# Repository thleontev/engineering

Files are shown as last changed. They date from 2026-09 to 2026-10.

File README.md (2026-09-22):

# Engineering

Репозиторий инженерных проектов и разработок.

Здесь собраны законченные и демонстрационные проекты по электронике, встроенному ПО, CAD, прототипированию и подготовке изделий к производству.

## Проекты

### Fire Lamp

Адресный LED-светильник на базе ESP32-S3 и WLED.

В проекте объединены:

- механическая конструкция и CAD;
- проектирование схемы и печатной платы;
- силовая часть для адресной LED-матрицы;
- встроенное ПО и пользовательский модуль WLED;
- датчик движения и датчик освещённости;
- сборка, прототипирование и испытания.

→ [Fire Lamp](fire-lamp/)

## Принцип публикации

В репозитории размещаются только материалы, которые подходят для публичного просмотра и воспроизведения проекта. Рабочие внутренние документы, данные поставщиков, учётные данные и незавершённые эксперименты не публикуются.

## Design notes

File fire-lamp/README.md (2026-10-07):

# Fire Lamp

Fire Lamp — настольный адресный LED-светильник с контроллером на ESP32-S3, матрицей WS2812B 16×16 и прошивкой на базе WLED.

Проект объединяет механику, электронику и встроенное ПО в одном изделии.

## Известная проблема

Несколько раз ESP32-S3 перезапускался в момент включения питания LED-матрицы после долгого выключения. Одна из возможных причин — большой пусковой ток. На выходе питания матрицы установлен конденсатор C14 на 470 мкФ, при включении он быстро заряжается и может на короткое время просаживать питание. Для следующей версии платы C14 лучше оставить как опциональный элемент (DNP) и устанавливать только если он действительно нужен после проверки питания.

## Основные узлы

- ESP32-S3;
- адресная LED-матрица WS2812B 16×16, 256 светодиодов;
- контроллер LumaCore-S3-PWR;
- PIR-датчик движения;
- датчик освещённости BH1750;
- питание 5 В;
- WLED с пользовательским модулем автоматического ночного режима.

## Структура

- [cad](cad/) — открытая механическая модель в формате STEP;
- [pcb](pcb/) — схема и печатная плата контроллера;
- [firmware](firmware/) — пользовательский модуль WLED и конфигурация;
- [docs](docs/) — архитектура и описание инженерных решений.

## Архитектура

```text
                         Fire Lamp
                             │
              ┌──────────────┼──────────────┐
              │              │              │
              ▼              ▼              ▼
           Корпус         LED 16×16     Датчики
              │              │          PIR + BH1750
              │              │              │
              └──────────────┼──────────────┘
                             ▼
                     LumaCore-S3-PWR
                             │
                             ▼
                         ESP32-S3
                             │
                             ▼
                       WLED + usermod
```

## Что демонстрирует проект

Проект охватывает полный цикл разработки небольшого электронного изделия:

- механическая компоновка и CAD;
- интеграция платы, матрицы и датчиков в корпус;
- разработка принципиальной схемы;
- разводка PCB;
- силовое питание адресных светодиодов;
- разработка встроенного ПО;
- интеграция датчиков;
- настройка сценариев автоматического управления;
- прототипирование и проверка работы устройства.

## Механическая модель

- [Сборка Fire Lamp R1.2 в формате STEP](cad/fire-lamp-assembly.step)

## Галерея

Изображения Fire Lamp. Нажмите на изображение, чтобы открыть оригинал.

| | |
| --- | --- |
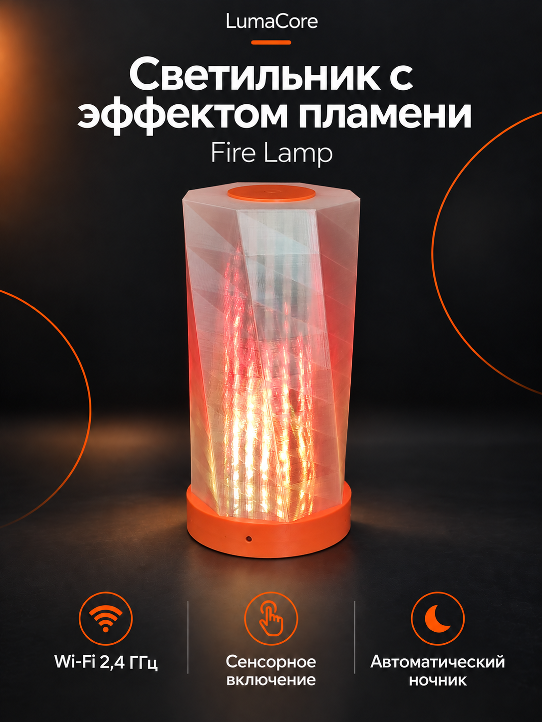
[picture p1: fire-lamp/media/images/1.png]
Fire Lamp — общий вид
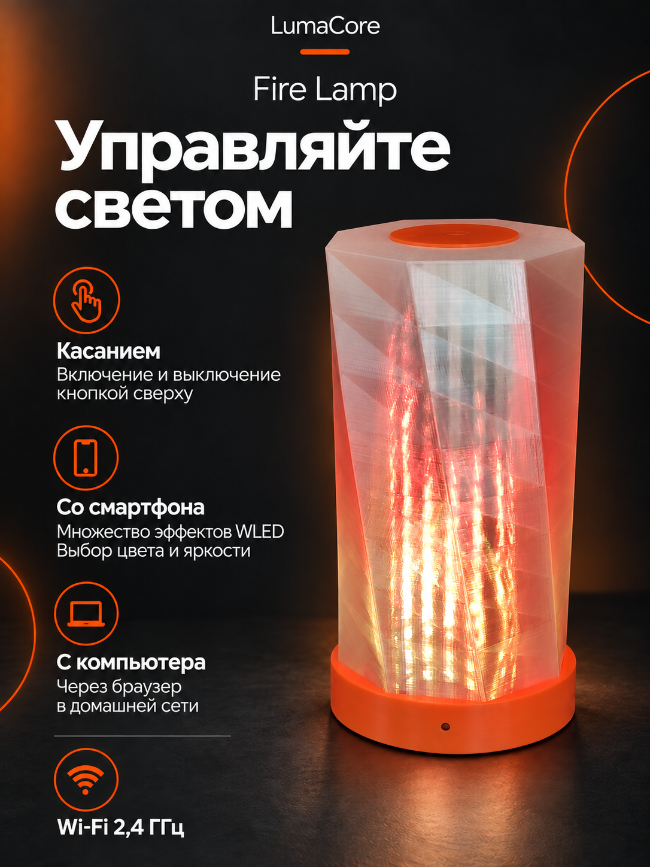
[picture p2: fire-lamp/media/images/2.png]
Управление светом
|  |  |
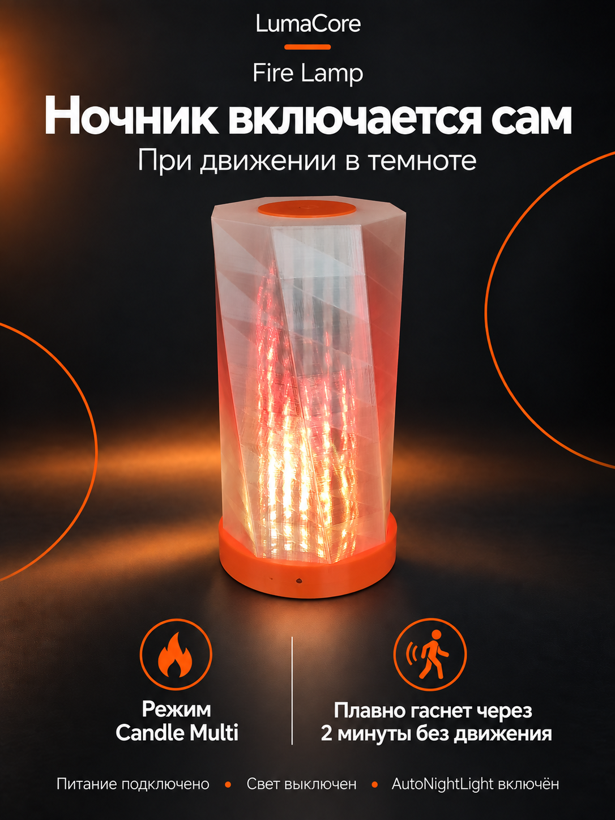
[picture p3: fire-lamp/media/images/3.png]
Автоматический ночник
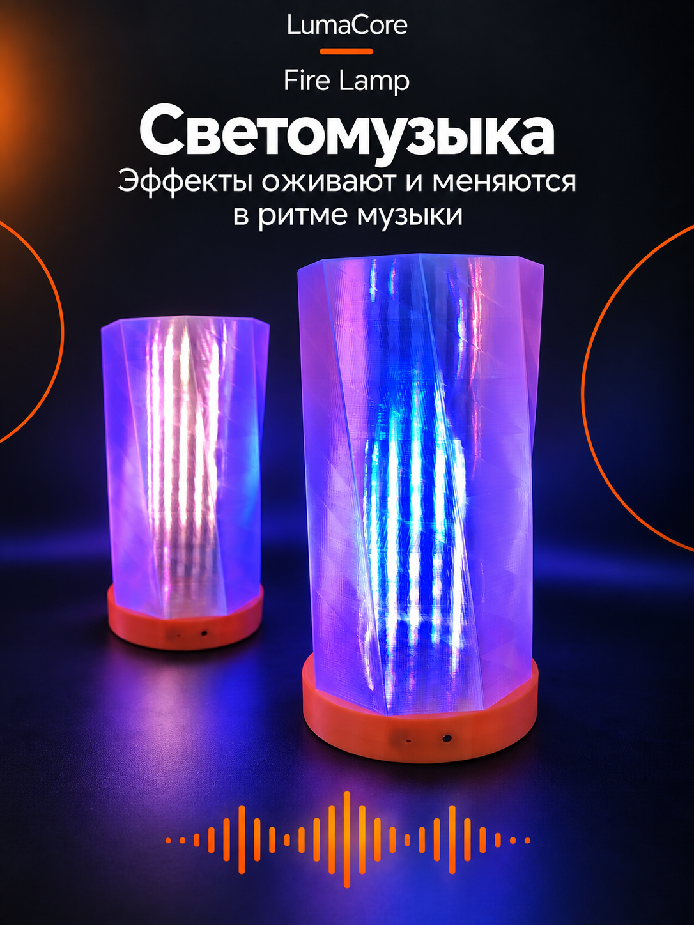
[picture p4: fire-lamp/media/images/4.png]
Светомузыка
|  |  |
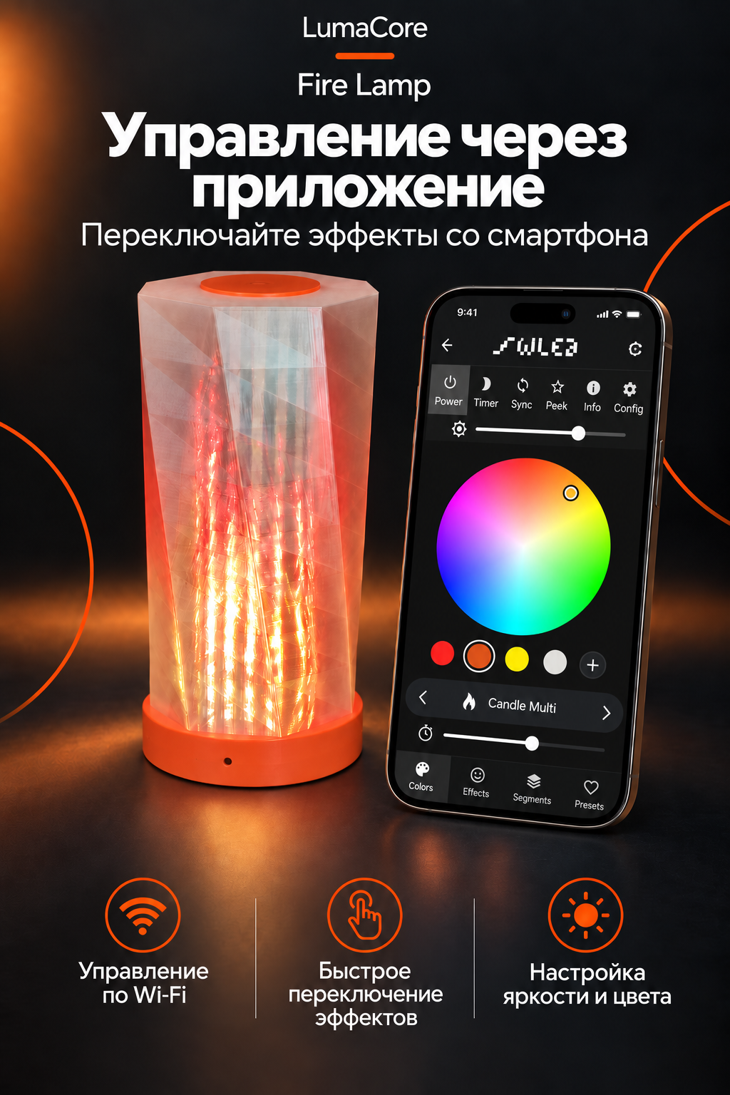
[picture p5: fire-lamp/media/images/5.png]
Управление через приложение
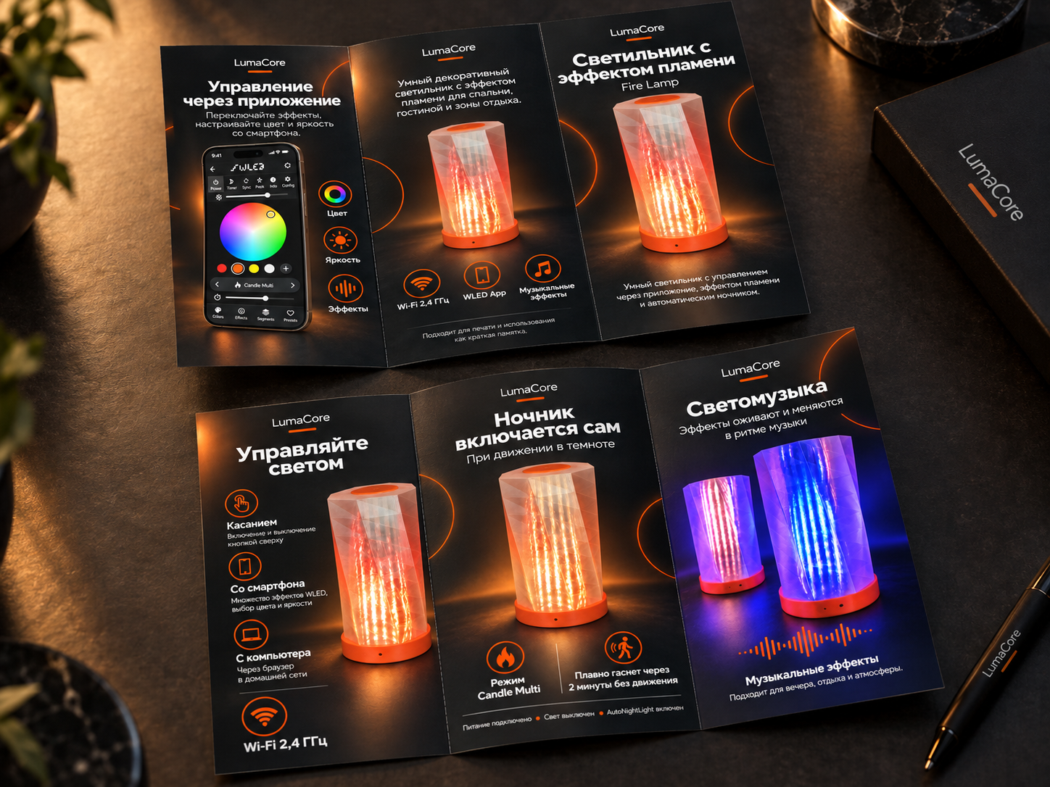
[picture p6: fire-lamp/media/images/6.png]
Буклет Fire Lamp
|  |  |
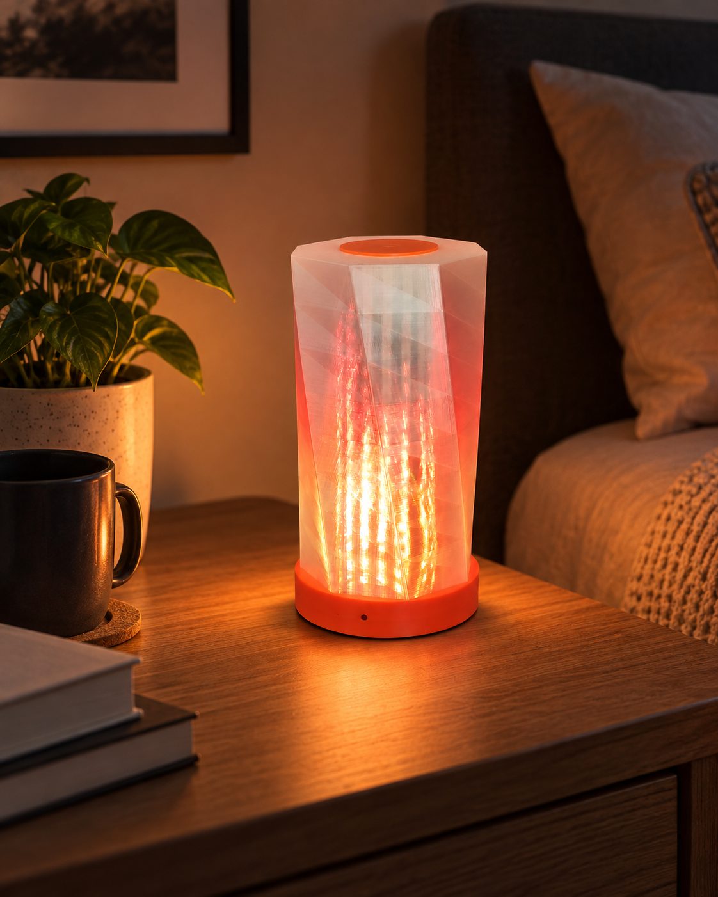
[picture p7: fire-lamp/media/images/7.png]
Fire Lamp в интерьере
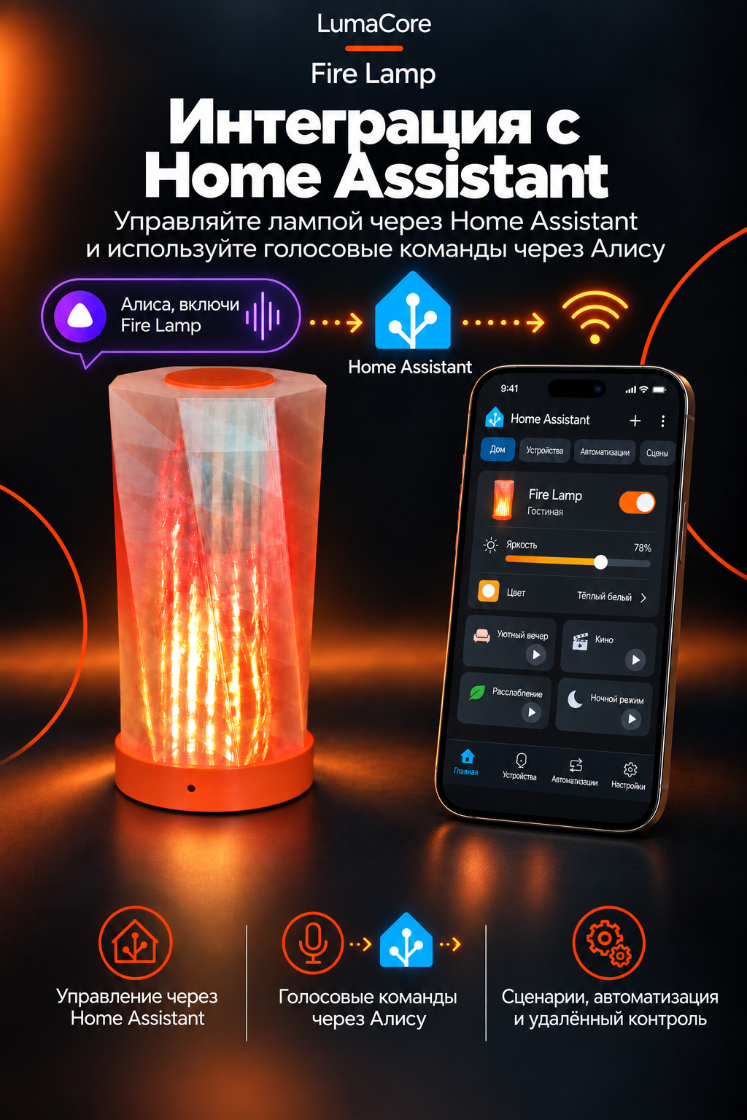
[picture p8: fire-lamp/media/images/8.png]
Интеграция с Home Assistant
|  |  |

## Видео

- [Видео history.mp4](media/video/history.mp4)
- [Демонстрация работы Fire Lamp](media/video/VID_20260911_115708.mp4)

## Состояние публикации

Публичная версия содержит только материалы, предназначенные для открытого использования. Нативные CAD-файлы КОМПАС-3D и внутренние рабочие материалы не публикуются.

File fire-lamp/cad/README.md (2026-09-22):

# CAD

Механические материалы Fire Lamp опубликованы в форматах STEP, STL и 3MF.

Нативные исходники КОМПАС-3D, Rhino и Grasshopper в этот репозиторий не включаются.

## Ревизия

Опубликована сборочная модель из каталога механической ревизии R1.2.

## STEP

- [Скачать полную сборку Fire Lamp в формате STEP](fire-lamp-assembly.step)

## Экспорт R1.2

Файлы из каталога экспорта механической ревизии R1.2:

- [Крышка — STL](export/R1.2/крышка.stl)
- [Плафон — STL](export/R1.2/плафон.stl)
- [Подставка — STL](export/R1.2/подставка.stl)
- [Центр — STL](export/R1.2/центр.stl)
- [Fire Lamp — 3MF](export/R1.2/fire%20lamp.3mf)

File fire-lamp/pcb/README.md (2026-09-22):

# PCB — LumaCore-S3-PWR

Электроника Fire Lamp построена на контроллере LumaCore-S3-PWR.

## Рендеры платы

### Верхняя сторона

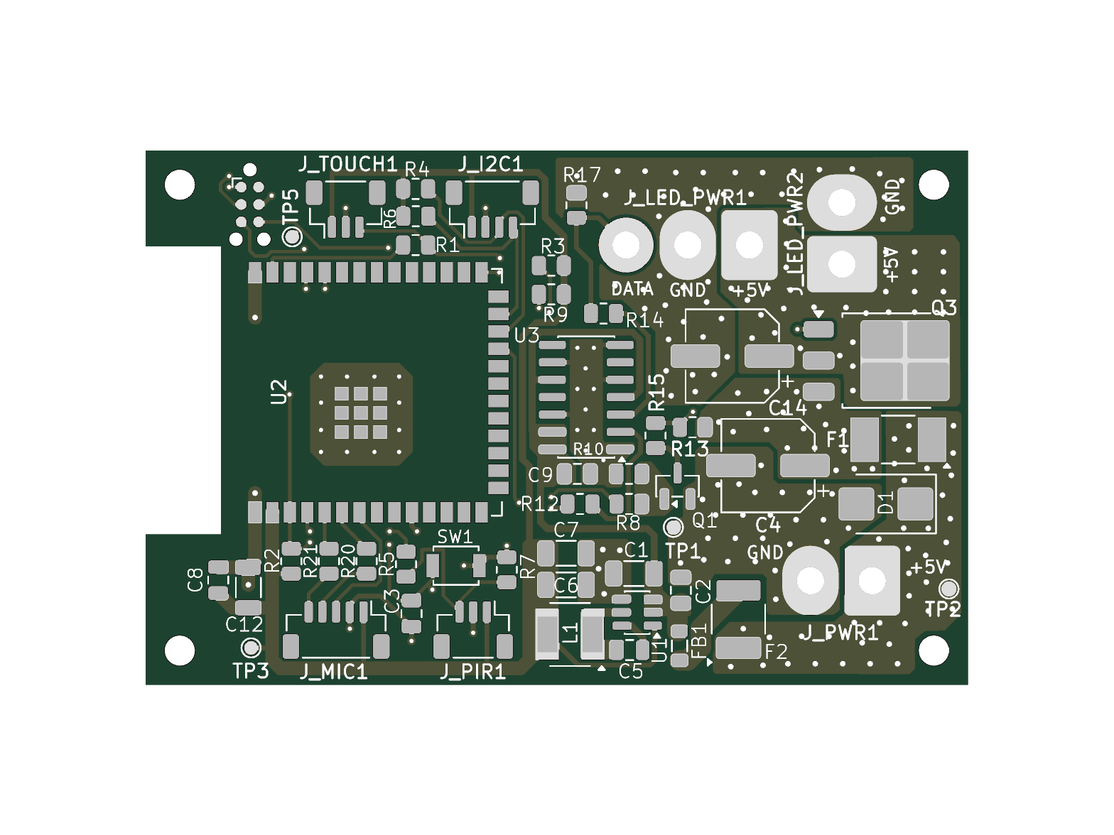
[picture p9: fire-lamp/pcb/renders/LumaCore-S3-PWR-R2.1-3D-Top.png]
LumaCore-S3-PWR R2.1 — верхняя сторона


### Нижняя сторона

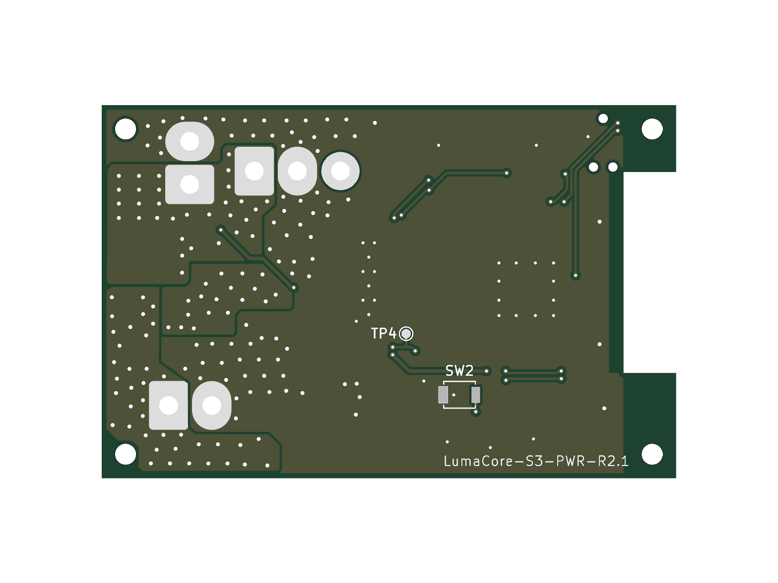
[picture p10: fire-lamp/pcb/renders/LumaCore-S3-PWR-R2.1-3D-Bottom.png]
LumaCore-S3-PWR R2.1 — нижняя сторона


## Исходники

В каталоге `source/` находятся исходники KiCad:

- проект;
- принципиальная схема;
- печатная плата.

В каталоге `production/` размещены открытые производственные данные, которые можно использовать для анализа платы и подготовки сборки.

## Основные параметры

- MCU: ESP32-S3-WROOM-1;
- питание изделия: 5 В;
- нагрузка: WS2812B 16×16;
- LED DATA: отдельный буферизированный цифровой выход;
- управление питанием LED;
- отдельное питание логики 3,3 В.

## Ревизия

Опубликованный набор PCB основан на LumaCore-S3-PWR R2.1.

Плата является частью проекта Fire Lamp, но может использоваться и как самостоятельная аппаратная платформа.

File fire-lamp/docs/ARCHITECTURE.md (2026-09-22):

# Архитектура Fire Lamp

## Назначение

Fire Lamp — автономный адресный светильник, в котором один контроллер управляет LED-матрицей и обрабатывает локальные датчики.

## Функциональная схема

```text
5 V DC
  │
  ├──────────────→ LED matrix WS2812B 16×16
  │
  └→ LumaCore-S3-PWR
          │
          ├→ ESP32-S3
          ├→ LED DATA
          ├→ PIR
          └→ BH1750
                │
                ▼
              WLED
                │
                └→ AutoNightLight usermod
```

## Контроллер

Основой электроники является LumaCore-S3-PWR — плата управления на ESP32-S3, рассчитанная на работу с адресными светодиодами и внешними датчиками.

## LED-матрица

Используется матрица WS2812B 16×16, всего 256 пикселей. Управление выполняется одним цифровым каналом DATA.

## Автоматический режим

Пользовательский модуль WLED использует два сигнала:

- PIR — наличие движения;
- BH1750 — текущая освещённость.

При низкой освещённости и обнаружении движения модуль может включить заданный WLED preset. После прекращения движения запускается задержка выключения. Ручное управление имеет приоритет над автоматикой.

## Разделение проекта

Механика, PCB и firmware публикуются раздельными каталогами, но относятся к одному изделию и должны рассматриваться совместно.

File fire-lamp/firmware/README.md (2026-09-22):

# Firmware

Fire Lamp использует WLED с пользовательским модулем LumaCore AutoNightLight.

Полный исходный код upstream WLED в этот репозиторий не дублируется. Здесь публикуются только изменения и настройки, относящиеся к Fire Lamp.

## Возможности AutoNightLight

Модуль объединяет:

- PIR-датчик движения;
- BH1750;
- автоматический запуск выбранного preset;
- задержку выключения;
- плавное включение и выключение;
- сохранение предыдущего состояния WLED в RAM;
- приоритет ручного управления.

## Логика

1. Проверяется уровень освещённости.
2. Если достаточно темно, разрешается реакция на PIR.
3. При обнаружении движения включается заданный preset.
4. После окончания движения запускается таймер.
5. По завершении таймера светильник выключается.
6. Если пользователь вручную выключил свет, автоматика не включает его повторно до завершения текущего события движения.

## Содержимое

- `usermod/` — исходный код пользовательского модуля;
- `config/` — пример конфигурации без паролей и данных конкретного устройства.

Конфигурационные файлы являются шаблонами. Учётные данные Wi-Fi, OTA, MQTT и другие секреты в репозиторий не включаются.

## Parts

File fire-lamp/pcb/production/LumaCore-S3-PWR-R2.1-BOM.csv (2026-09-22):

Refs | Qty | Value | Footprint | Manufacturer | MPN | Supplier | Description | Specification
C1 | 1 | 10uF | Capacitor_SMD:C_1206_3216Metric |  |  |  | Unpolarized capacitor, small symbol | 10uF; 10V; X5R; ±10%; 1206
C2, C5, C9, C12 | 4 | 100nF | Capacitor_SMD:C_0805_2012Metric |  |  |  | Unpolarized capacitor, small symbol | 100nF; 50V; X7R; ±10%; 0805
C3 | 1 | 1uF | Capacitor_SMD:C_0805_2012Metric |  |  |  | Unpolarized capacitor, small symbol | 1uF; 16V; X7R; ±10%; 0805
C4, C14 | 2 | 470uF | Capacitor_SMD:CP_Elec_6.3x7.7 |  | EEEFTA471XAP |  | 470uF 10V 105C SMD D6.3x7.7 | 470uF; 10V; 105°C; SMD 6.3x7.7mm
C6-C8 | 3 | 22uF | Capacitor_SMD:C_1206_3216Metric |  |  |  | Unpolarized capacitor, small symbol | 22uF; 10V; X7R; ±10%; 1206
D1 | 1 | SMBJ5.0A | Diode_SMD:D_SMB |  | SMBJ5.0A |  | Unidirectional TVS diode, 600W, 5V, SMB / DO-214AA | TVS; SMBJ5.0A; 5.0V; 600W; SMB (DO-214AA)
F1 | 1 | 10A, 125V, 2410 | LumaCore:Fuse_Littelfuse_NANO2_452_2410 |  | 0451010.MRL |  | 10A, 125V, 2410 | Fuse; 10A; 125V; 2410
F2 | 1 | PPTC 1.1A | LumaCore:Fuse_Polyfuse_Bourns_MF-MSMF110-16-2_1812 |  | MF-MSMF110/16-2 |  | PPTC resettable fuse, 1.1A hold, 2.2A trip, 16V, 1812 | PPTC; Ihold 1.1A; Vmax 16V; 1812
FB1 | 1 | Ferrite Bead | Inductor_SMD:L_0805_2012Metric |  | BLM21PG121SN1D |  | Ferrite bead, 120Ω @100MHz, 3A, 30mΩ max, 0805/2012, Murata BLM21PG series | Ferrite bead; 120Ω @100MHz; 3A; 0805
J_I2C1 | 1 | JST-SH 4pin | Connector_JST:JST_SH_BM04B-SRSS-TB_1x04-1MP_P1.00mm_Vertical |  |  |  | Generic connector, single row, 01x04, script generated (kicad-library-utils/schlib/autogen/connector/) | JST SH; 4 pin; 1.0mm; vertical SMD
J_MIC1 | 1 | JST-SH 5pin | Connector_JST:JST_SH_BM05B-SRSS-TB_1x05-1MP_P1.00mm_Vertical |  |  |  | Generic connector, single row, 01x05, script generated (kicad-library-utils/schlib/autogen/connector/) | JST SH; 5 pin; 1.0mm; vertical SMD
J_PIR1, J_TOUCH1 | 2 | JST-SH 3pin | Connector_JST:JST_SH_BM03B-SRSS-TB_1x03-1MP_P1.00mm_Vertical |  |  |  | Generic connector, single row, 01x03, script generated (kicad-library-utils/schlib/autogen/connector/) | JST SH; 3 pin; 1.0mm; vertical SMD
L1 | 1 | 3.9uH | LumaCore:L_4020_4030_Universal_LumaCore |  | MNR4030T3R9MT |  | Inductor | Inductor; 3.9uH; ±20%; current rating ≥3.3A; SMD 4x4mm
Q1 | 1 | 2N7002 | Package_TO_SOT_SMD:SOT-23 |  | 2N7002 |  | N-channel MOSFET, 60V, 115mA, SOT-23-3 | N-MOSFET; VDS ≥60V; ID ≥115mA; SOT-23-3
Q3 | 1 | PMOS_30V_6mR_TO252 | Package_TO_SOT_SMD:TO-252-3_TabPin2 |  | G050P03K |  | P-MOSFET, -30 V, RDS(on) ≤6 mΩ @ VGS=-4.5 V, TO-252, 1G-2D-3S | P-MOSFET; VDS -30V; RDS(on) ≤6mΩ @ VGS -4.5V; TO-252; 1G-2D-3S
R1, R5, R8, R12, R15 | 5 | 100 | Resistor_SMD:R_0805_2012Metric |  |  |  | Resistor, small symbol | 100Ω; ±1%; 0.125W; 0805; thick-film
R2, R9 | 2 | 10k | Resistor_SMD:R_0805_2012Metric |  |  |  | Resistor, small symbol | 10kΩ; ±1%; 0.125W; 0805; thick-film
R4, R6 | 2 | 4.7k | Resistor_SMD:R_0805_2012Metric |  |  |  | Resistor, small symbol | 4.7kΩ; ±1%; 0.125W; 0805; thick-film
R7, R10, R13, R17 | 4 | 100k | Resistor_SMD:R_0805_2012Metric |  |  |  | Resistor, small symbol | 100kΩ; ±1%; 0.125W; 0805; thick-film
R14 | 1 | 330 | Resistor_SMD:R_0805_2012Metric |  |  |  | Resistor, small symbol | 330Ω; ±1%; 0.125W; 0805; thick-film
R20, R21 | 2 | 33 | Resistor_SMD:R_0805_2012Metric |  |  |  | Resistor, small symbol | 33Ω; ±1%; 0.125W; 0805; thick-film
SW1 | 1 | Reset | Button_Switch_SMD:SW_SPST_B3U-1000P |  | B3U-1000P |  | Push button switch, generic, two pins | Tactile switch; SPST; B3U-1000P; SMD
U1 | 1 | AP63203WU | Package_TO_SOT_SMD:TSOT-23-6 |  | AP63203WU-7 |  | 2A, 1.1MHz Buck DC/DC Converter, fixed 3.3V output voltage, TSOT-23-6 | Buck DC/DC; 3.3V output; 2A; 1.1MHz; TSOT-23-6
U2 | 1 | ESP32-S3-WROOM-1 | LumaCore:ESP32-S3-WROOM-1 |  | ESP32-S3-WROOM-1(16R8) |  | 2.4 GHz WiFi (802.11 b/g/n) and Bluetooth ® 5 (LE) module Built around ESP32S3 series of SoCs, Xtensa ® dualcore 32bit LX7 microprocessor Flash up to 16 MB, PSRAM up to 8 MB 36 GPIOs, rich set of peripherals Onboard PCB antenna | ESP32-S3-WROOM-1(16R8); Wi-Fi/BLE; PCB antenna
U3 | 1 | 74AHCT125 | Package_SO:SOIC-14_3.9x8.7mm_P1.27mm |  | SN74AHCT125DR |  | Quadruple Bus Buffer Gates With 3-State Outputs | 74AHCT125; 5V logic buffer; SOIC-14

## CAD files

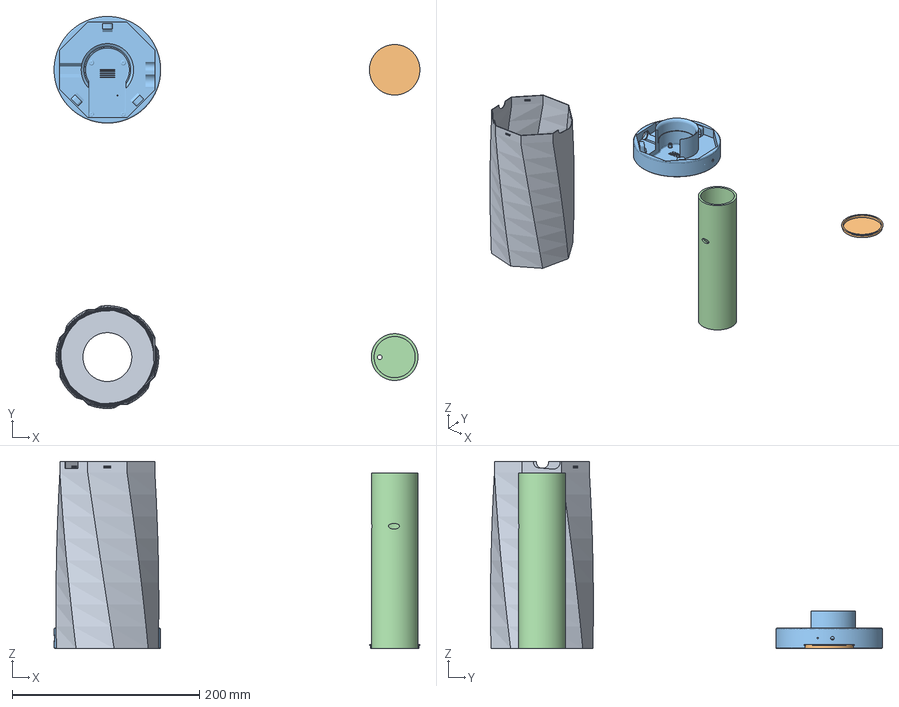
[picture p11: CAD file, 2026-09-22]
fire-lamp/cad/export/R1.2/fire lamp.3mf
391.2 x 419.2 x 200.0 mm
плафон.stl
крышка.stl
подставка.stl
центр.stl

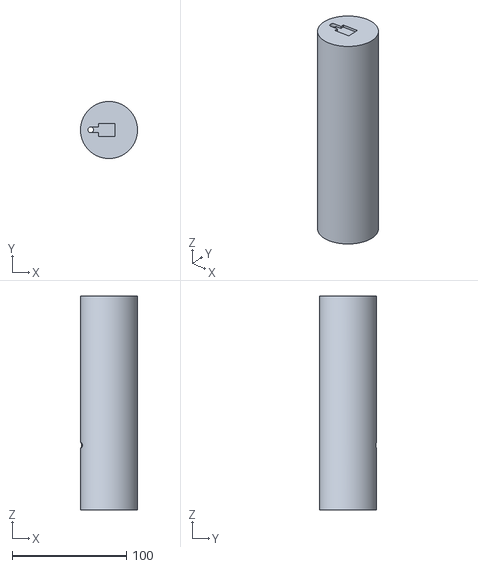
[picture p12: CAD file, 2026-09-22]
fire-lamp/cad/export/R1.2/центр.stl
50.0 x 50.0 x 187.5

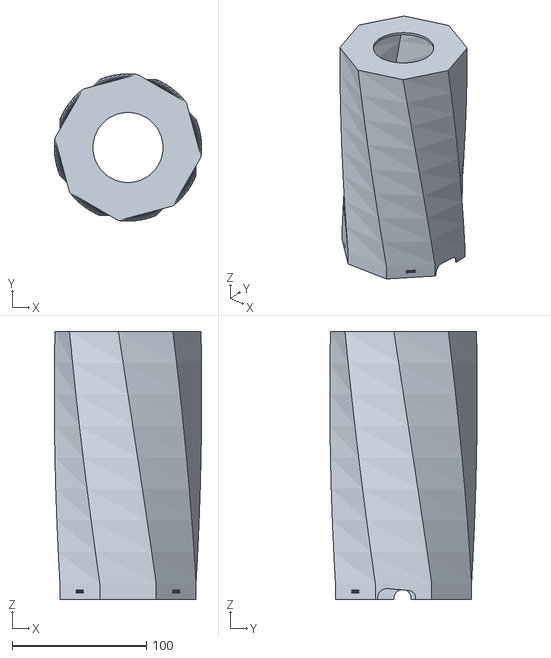
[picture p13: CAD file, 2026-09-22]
fire-lamp/cad/export/R1.2/плафон.stl
110.0 x 110.0 x 200.0

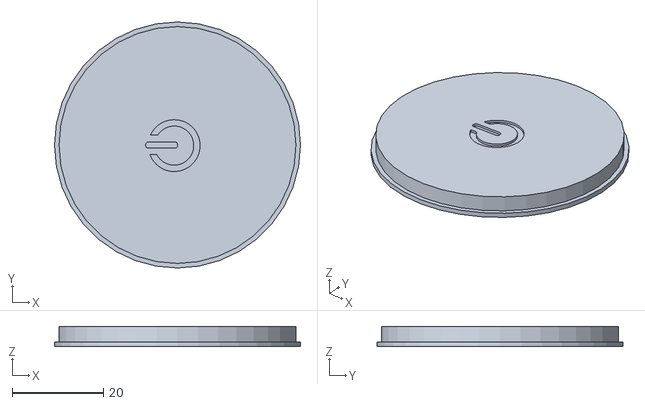
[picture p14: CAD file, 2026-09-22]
fire-lamp/cad/export/R1.2/крышка.stl
54.0 x 54.0 x 4.40

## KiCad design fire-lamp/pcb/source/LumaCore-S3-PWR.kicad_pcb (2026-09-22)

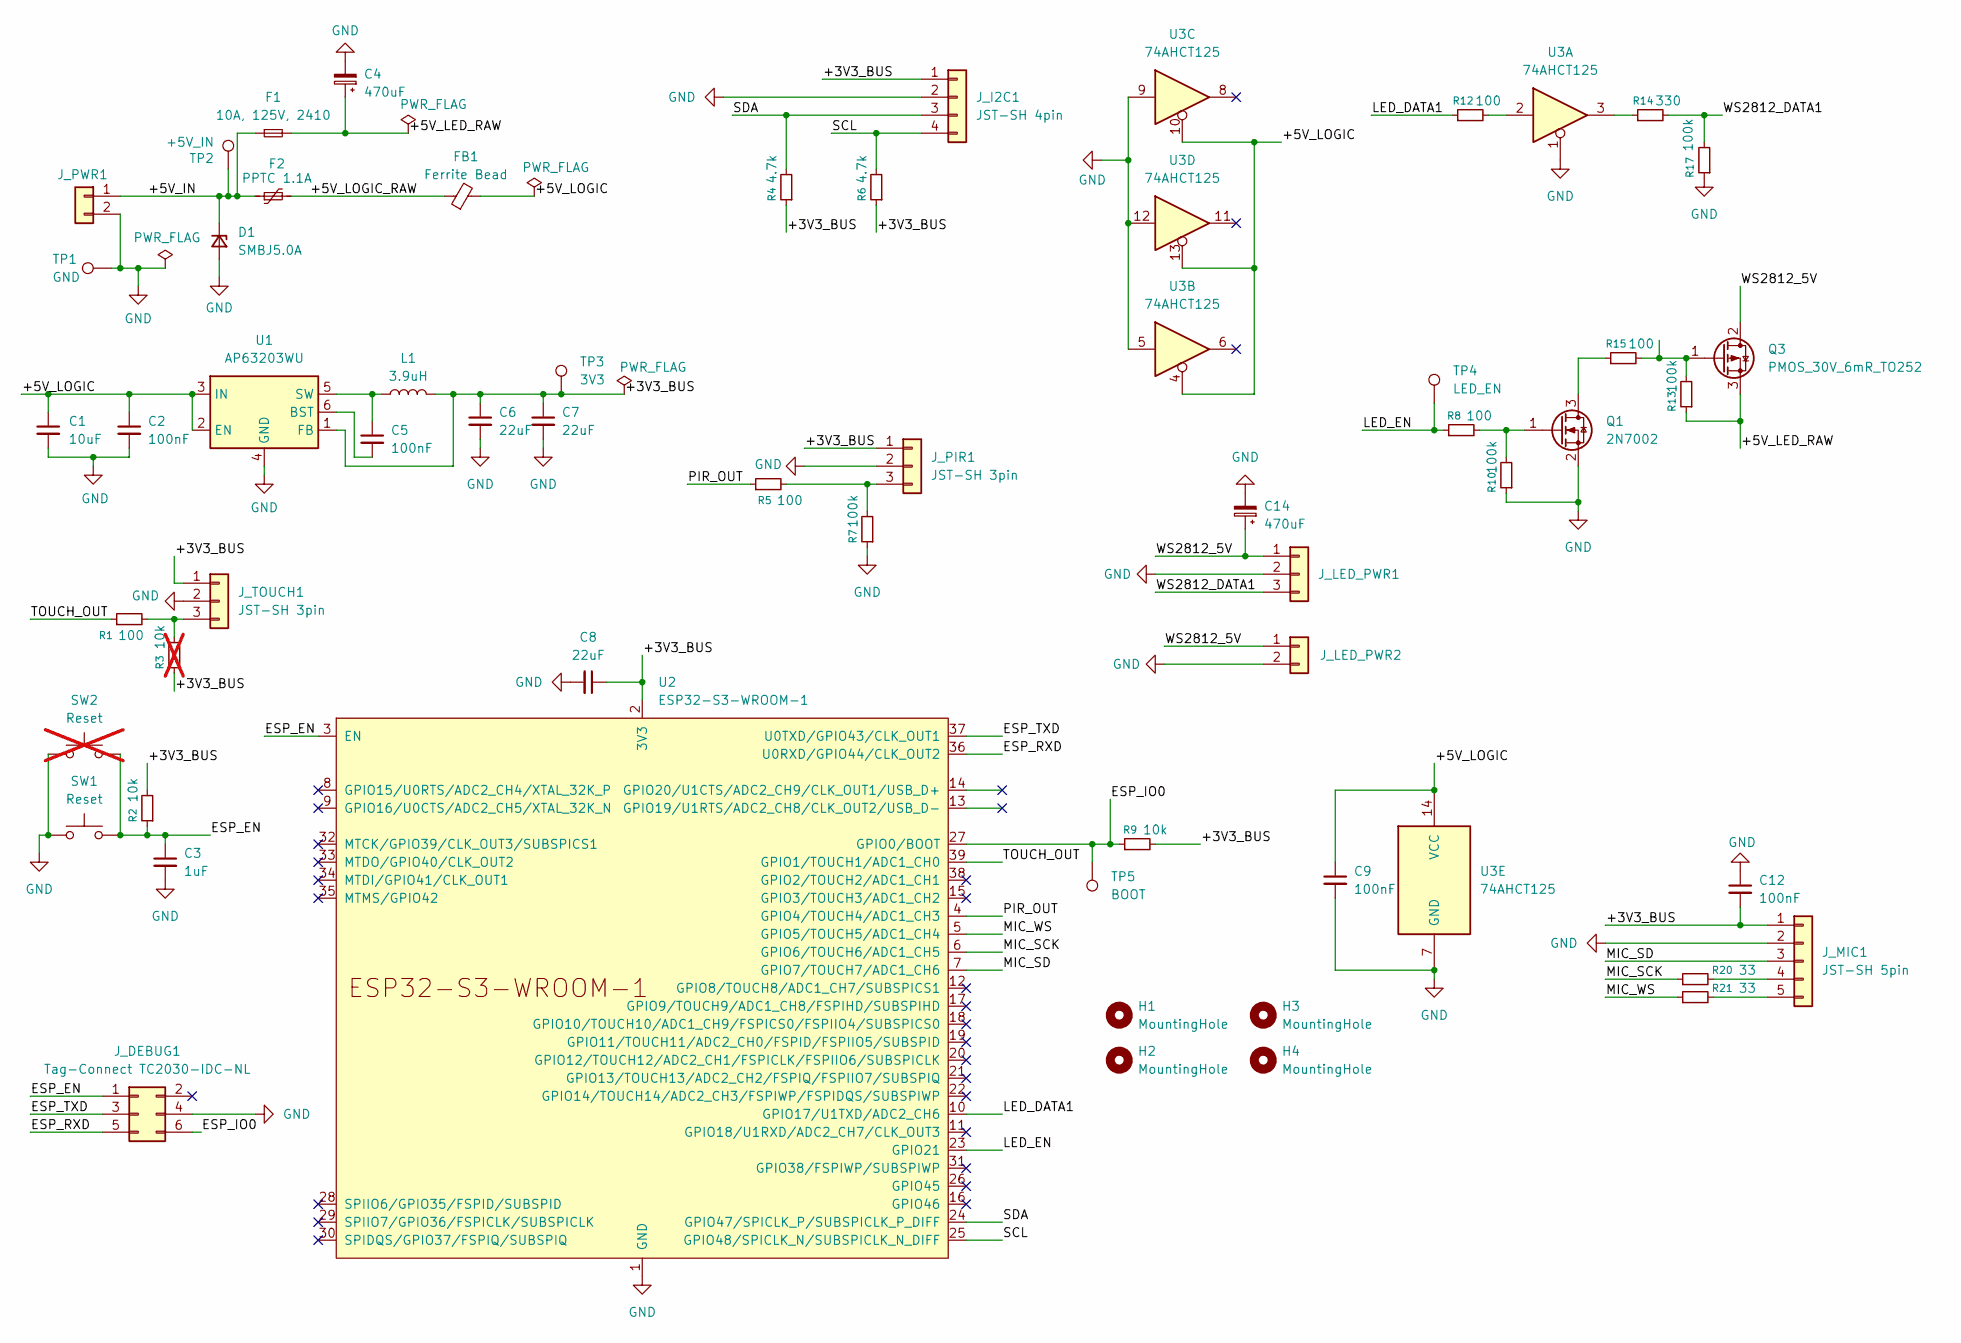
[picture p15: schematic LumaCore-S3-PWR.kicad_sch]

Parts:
C1: 10uF; C_1206_3216Metric
C2, C5, C9, C12: 100nF; C_0805_2012Metric
C3: 1uF; C_0805_2012Metric
C4, C14: 470uF; CP_Elec_6.3x7.7; MPN EEEFTA471XAP
C6, C7, C8: 22uF; C_1206_3216Metric
D1: SMBJ5.0A; D_SMB; MPN SMBJ5.0A
F1: 10A, 125V, 2410; Fuse_Littelfuse_NANO2_452_2410; MPN 0451010.MRL
F2: PPTC 1.1A; Fuse_Polyfuse_Bourns_MF-MSMF110-16-2_1812; MPN MF-MSMF110/16-2
FB1: Ferrite Bead; L_0805_2012Metric; MPN BLM21PG121SN1D
H1, H2, H3, H4: MountingHole; MountingHole_2.2mm_M2
J_DEBUG1: Tag-Connect TC2030-IDC-NL; Tag-Connect_TC2030-IDC-NL_2x03_P1.27mm_Vertical
J_I2C1: JST-SH 4pin; JST_SH_BM04B-SRSS-TB_1x04-1MP_P1.00mm_Vertical
J_LED_PWR1: SolderCable_1x03_AWG16_DATA_P4.50_D2.00
J_LED_PWR2: SolderCable_1x02_AWG16_P4.50_D2.00
J_MIC1: JST-SH 5pin; JST_SH_BM05B-SRSS-TB_1x05-1MP_P1.00mm_Vertical
J_PIR1: JST-SH 3pin; JST_SH_BM03B-SRSS-TB_1x03-1MP_P1.00mm_Vertical
J_PWR1: SolderCable_1x02_AWG16_P4.50_D2.00
J_TOUCH1: JST-SH 3pin; JST_SH_BM03B-SRSS-TB_1x03-1MP_P1.00mm_Vertical
L1: 3.9uH; L_4020_4030_Universal_LumaCore; MPN MNR4030T3R9MT
Q1: 2N7002; SOT-23; MPN 2N7002
Q3: PMOS_30V_6mR_TO252; TO-252-3_TabPin2; MPN G050P03K
R1, R5, R8, R12, R15: 100; R_0805_2012Metric
R2, R9: 10k; R_0805_2012Metric
R3: 10k; R_0805_2012Metric; not fitted
R4, R6: 4.7k; R_0805_2012Metric
R7, R10, R13, R17: 100k; R_0805_2012Metric
R14: 330; R_0805_2012Metric
R20, R21: 33; R_0805_2012Metric
SW1: Reset; SW_SPST_B3U-1000P; MPN B3U-1000P
SW2: Reset; SW_SPST_B3U-1000P; MPN B3U-1000P; not fitted
TP1: GND; TestPoint_Pad_D1.0mm
TP2: +5V_IN; TestPoint_Pad_D1.0mm
TP3: 3V3; TestPoint_Pad_D1.0mm
TP4: LED_EN; TestPoint_Pad_D1.0mm
TP5: BOOT; TestPoint_Pad_D1.0mm
U1: AP63203WU; TSOT-23-6; MPN AP63203WU-7
U2: ESP32-S3-WROOM-1; MPN ESP32-S3-WROOM-1(16R8)
U3: 74AHCT125; SOIC-14_3.9x8.7mm_P1.27mm; MPN SN74AHCT125DR

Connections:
/+3V3_BUS: C6.1, C7.1, C8.1, C12.2, J_I2C1.1, J_MIC1.1, J_PIR1.1, J_TOUCH1.1, L1.2, R2.2, R3.1, R4.1, R6.1, R9.2, TP3.1 (1_1), U1.1 (FB), U2.2 (3V3)
/+5V_IN: D1.1 (K), F1.1, F2.1, J_PWR1.1, TP2.1 (1_1)
/+5V_LED_RAW: C4.1, F1.2, Q3.3 (S), R13.1
/+5V_LOGIC: C1.1, C2.1, C9.1, FB1.2, U1.2 (EN), U1.3 (IN), U3.4, U3.10, U3.13, U3.14 (VCC)
/+5V_LOGIC_RAW: F2.2, FB1.1
/ESP_EN: C3.1, J_DEBUG1.1, R2.1, SW1.2, SW2.2, U2.3 (EN)
/ESP_IO0: J_DEBUG1.6, R9.1, TP5.1 (1_1), U2.27 (GPIO0/BOOT)
/ESP_RXD: J_DEBUG1.5, U2.36 (U0RXD/GPIO44/CLK_OUT2)
/ESP_TXD: J_DEBUG1.3, U2.37 (U0TXD/GPIO43/CLK_OUT1)
/LED_DATA1: R12.1, U2.10 (GPIO17/U1TXD/ADC2_CH6)
/LED_EN: R8.1, TP4.1 (1_1), U2.23 (GPIO21)
/MIC_SCK: R20.1, U2.6 (GPIO6/TOUCH6/ADC1_CH5)
/MIC_SD: J_MIC1.3, U2.7 (GPIO7/TOUCH7/ADC1_CH6)
/MIC_WS: R21.1, U2.5 (GPIO5/TOUCH5/ADC1_CH4)
/PIR_OUT: R5.1, U2.4 (GPIO4/TOUCH4/ADC1_CH3)
/SCL: J_I2C1.4, R6.2, U2.25 (GPIO48/SPICLK_N/SUBSPICLK_N_DIFF)
/SDA: J_I2C1.3, R4.2, U2.24 (GPIO47/SPICLK_P/SUBSPICLK_P_DIFF)
/TOUCH_OUT: R1.1, U2.39 (GPIO1/TOUCH1/ADC1_CH0)
/WS2812_5V: C14.1, J_LED_PWR1.1, J_LED_PWR2.1, Q3.2 (D)
/WS2812_DATA1: J_LED_PWR1.3, R14.2, R17.2
GND: C1.2, C2.2, C3.2, C4.2, C6.2, C7.2, C8.2, C9.2, C12.1, C14.2, D1.2 (A), J_DEBUG1.4, J_I2C1.2, J_LED_PWR1.2, J_LED_PWR2.2, J_MIC1.2, J_PIR1.2, J_PWR1.2, J_TOUCH1.2, Q1.2 (S), R7.1, R10.1, R17.1, SW1.1, SW2.1, TP1.1 (1_1), U1.4 (GND), U2.1 (GND), U2.40 (GND), U2.41 (GND), U3.1, U3.5, U3.7 (GND), U3.9, U3.12
unnamed: J_MIC1.4, R20.2
unnamed: J_MIC1.5, R21.2
unnamed: J_PIR1.3, R5.2, R7.2
unnamed: J_TOUCH1.3, R1.2, R3.2
unnamed: Q1.3 (D), R15.1
unnamed: Q1.1 (G), R8.2, R10.2
unnamed: Q3.1 (G), R13.2, R15.2
unnamed: R12.2, U3.2
unnamed: R14.1, U3.3
unnamed: C5.2, U1.6 (BST)
unnamed: C5.1, L1.1, U1.5 (SW)

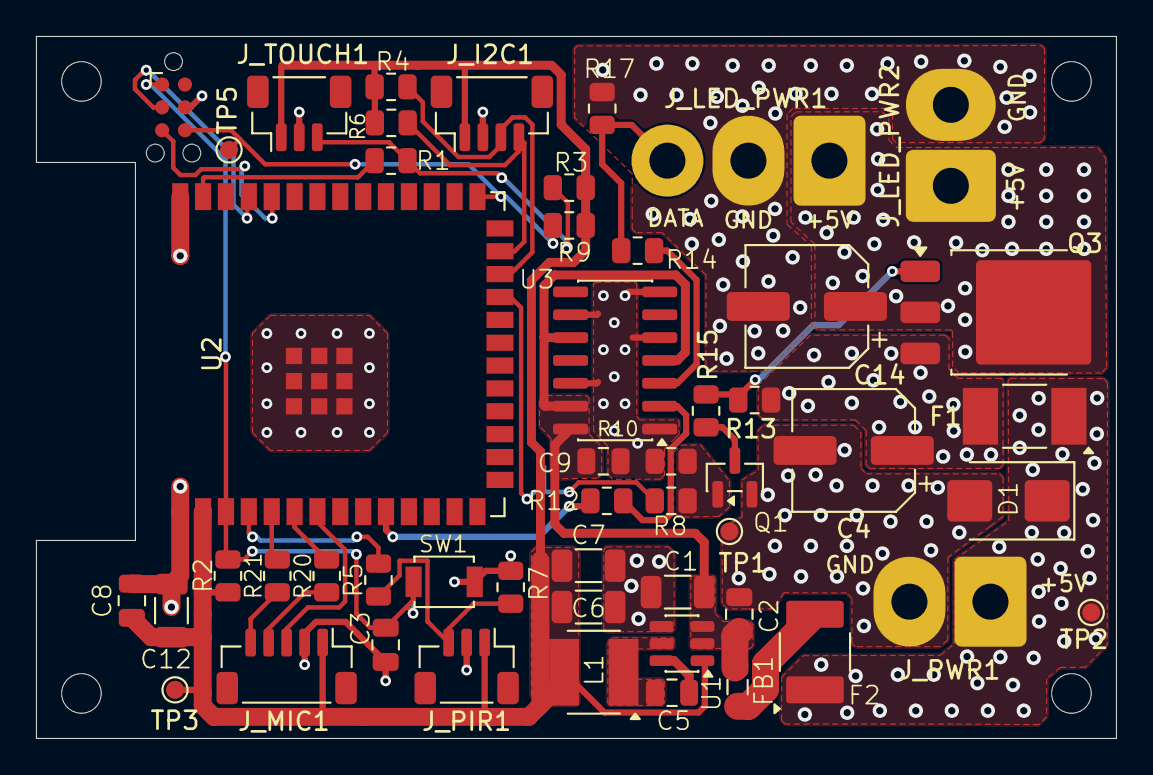
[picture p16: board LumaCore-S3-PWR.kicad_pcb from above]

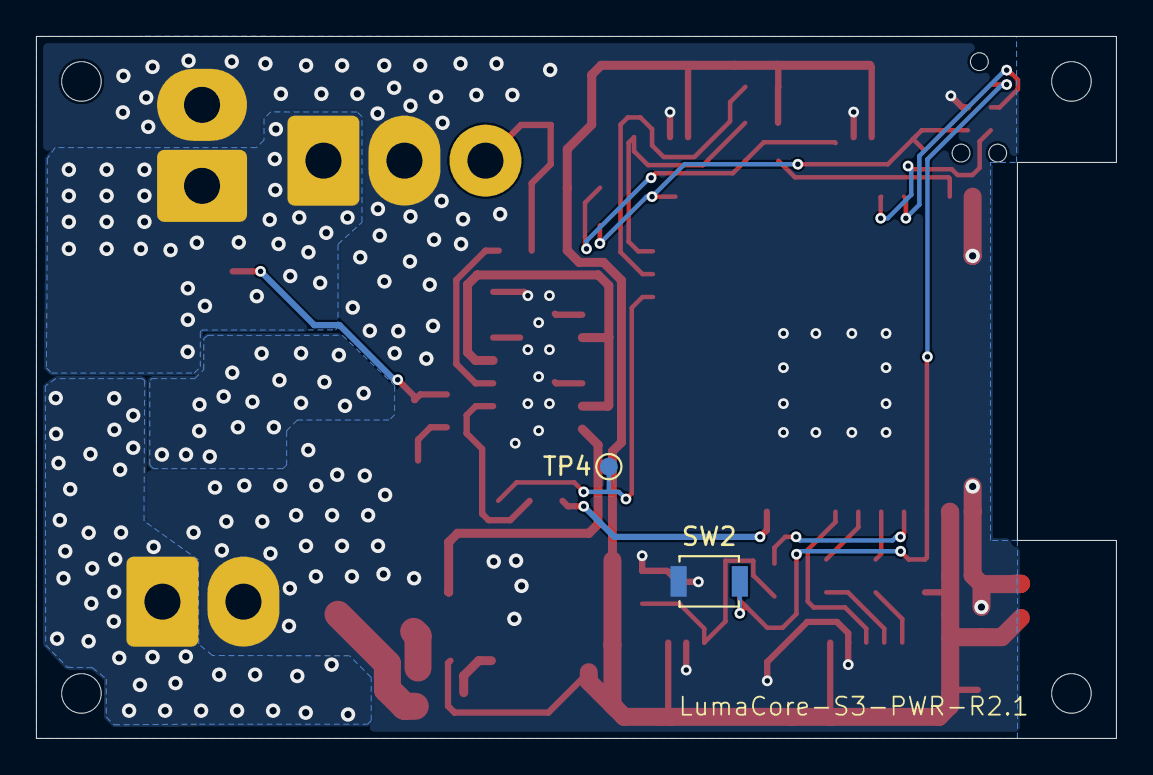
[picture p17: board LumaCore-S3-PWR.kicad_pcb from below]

Board: 2 copper layers, 60.0 x 39.0 mm, 57 parts (2 on the bottom side), 32 nets.

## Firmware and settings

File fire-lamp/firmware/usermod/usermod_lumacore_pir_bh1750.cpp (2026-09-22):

#include "usermod_lumacore_pir_bh1750.h"

#include <Wire.h>

static constexpr uint8_t BH1750_POWER_ON = 0x01;
static constexpr uint8_t BH1750_RESET = 0x07;
static constexpr uint8_t BH1750_CONTINUOUS_HIGH_RES_MODE = 0x10;
static constexpr uint16_t LUMACORE_PIR_CHECK_INTERVAL_MS = 100;
bool LumaCorePirBh1750Usermod::initI2c()
{
  sensorFound = false;
  luxValid = false;

  if (sdaPin < 0 || sclPin < 0) return false;

  PinManagerPinType i2cPins[2] = { { sdaPin, true }, { sclPin, true } };
  if (!PinManager::allocateMultiplePins(i2cPins, 2, PinOwner::HW_I2C)) {
    DEBUG_PRINTLN(F("LumaCore: could not allocate I2C pins."));
    return false;
  }

  i2cPinsAllocated = true;
  Wire.begin(sdaPin, sclPin);
  Wire.setClock(100000);
  return true;
}

bool LumaCorePirBh1750Usermod::writeBh1750Command(uint8_t command)
{
  Wire.beginTransmission(bh1750Address);
  Wire.write(command);
  return Wire.endTransmission() == 0;
}

bool LumaCorePirBh1750Usermod::initBh1750()
{
  if (!writeBh1750Command(BH1750_POWER_ON)) return false;
  writeBh1750Command(BH1750_RESET);
  return writeBh1750Command(BH1750_CONTINUOUS_HIGH_RES_MODE);
}

bool LumaCorePirBh1750Usermod::readBh1750Lux()
{
  if (!sensorFound) {
    sensorFound = initBh1750();
    if (!sensorFound) {
      luxValid = false;
      return false;
    }
  }

  uint8_t bytesRead = Wire.requestFrom(bh1750Address, static_cast<uint8_t>(2));
  if (bytesRead != 2) {
    sensorFound = false;
    luxValid = false;
    return false;
  }

  uint16_t raw = (static_cast<uint16_t>(Wire.read()) << 8) | Wire.read();
  lastLux = raw / 1.2f;
  luxValid = true;
  return true;
}

void LumaCorePirBh1750Usermod::readPir()
{
  if (!pirPinAllocated) {
    rawPirHigh = false;
    pirActive = false;
    return;
  }

  rawPirHigh = digitalRead(pirPin) == HIGH;
  pirActive = pirActiveHigh ? rawPirHigh : !rawPirHigh;
}

bool LumaCorePirBh1750Usermod::isDark() const
{
  return luxValid && lastLux < luxThreshold;
}

bool LumaCorePirBh1750Usermod::isPirOwnedState() const
{
  return nightLightState == NightLightState::AutoOn || nightLightState == NightLightState::WaitingOff;
}

void LumaCorePirBh1750Usermod::setNightLightState(NightLightState newState)
{
  nightLightState = newState;

  if (newState == NightLightState::WaitingOff) {
    if (!offTimerStart) offTimerStart = millis();
  } else {
    offTimerStart = 0;
  }
}

void LumaCorePirBh1750Usermod::clearPreviousState()
{
  p_free(previousStateJson);
  previousStateJson = nullptr;
  previousStateJsonLen = 0;
  previousStateSaved = false;
  previousCurrentPreset = 0;
  previousPresetCycCurr = 0;
  previousCurrentPlaylist = -1;
}

bool LumaCorePirBh1750Usermod::capturePreviousState()
{
  clearPreviousState();

  DynamicJsonDocument stateDoc(JSON_BUFFER_SIZE);
  JsonObject state = stateDoc.to<JsonObject>();
  serializeState(state);
  state["on"] = false;
  state.remove(F("ps"));
  state.remove(F("pl"));
  state.remove(F("psave"));
  state.remove(F("pdel"));

  if (stateDoc.overflowed()) {
    DEBUG_PRINTLN(F("LumaCore: previous state snapshot overflowed."));
    clearPreviousState();
    return false;
  }

  previousCurrentPreset = currentPreset;
  previousPresetCycCurr = presetCycCurr;
  previousCurrentPlaylist = currentPlaylist;
  previousStateJsonLen = measureJson(stateDoc) + 1;
  previousStateJson = static_cast<char*>(p_malloc(previousStateJsonLen));
  if (!previousStateJson) {
    DEBUG_PRINTLN(F("LumaCore: could not allocate previous state snapshot."));
    clearPreviousState();
    return false;
  }

  serializeJson(stateDoc, previousStateJson, previousStateJsonLen);
  previousStateSaved = true;
  return true;
}

bool LumaCorePirBh1750Usermod::restorePreviousStateKeepingOff()
{
  if (!previousStateSaved || !previousStateJson) return false;

  byte restoredPreset = previousCurrentPreset;
  byte restoredPresetCyc = previousPresetCycCurr;
  int16_t restoredPlaylist = previousCurrentPlaylist;

  DynamicJsonDocument stateDoc(JSON_BUFFER_SIZE);
  DeserializationError error = deserializeJson(stateDoc, previousStateJson);
  if (error) {
    DEBUG_PRINTLN(F("LumaCore: could not deserialize previous state snapshot."));
    clearPreviousState();
    return false;
  }

  JsonObject state = stateDoc.as<JsonObject>();
  state["on"] = false;
  state.remove(F("ps"));
  state.remove(F("pl"));
  state.remove(F("psave"));
  state.remove(F("pdel"));

  ownStateChange = true;
  deserializeState(state, CALL_MODE_NO_NOTIFY);

  if (bri > 0) {
    briLast = bri;
    bri = 0;
    stateChanged = true;
    ownStateChange = true;
    stateUpdated(CALL_MODE_NO_NOTIFY);
  }

  if (restoredPlaylist < 0 && restoredPreset > 0) {
    currentPreset = restoredPreset;
    presetCycCurr = restoredPresetCyc;
  }

  clearPreviousState();
  return true;
}

void LumaCorePirBh1750Usermod::setOneShotTransition(uint8_t seconds)
{
  uint32_t duration = static_cast<uint32_t>(seconds) * 1000U;
  if (duration > UINT16_MAX) duration = UINT16_MAX;
  transitionDelay = static_cast<uint16_t>(duration);
  jsonTransitionOnce = true;
  strip.setTransition(transitionDelay);
}

void LumaCorePirBh1750Usermod::switchOnByPir()
{
  if (bri > 0 || nightLightState != NightLightState::Idle) return;
  if (!capturePreviousState()) return;

  setOneShotTransition(transitionSec);
  ownStateChange = true;

  if (onPreset > 0) {
    applyPreset(onPreset, CALL_MODE_BUTTON_PRESET);
  } else {
    bri = briLast ? briLast : briS;
    strip.restartRuntime();
    stateChanged = true;
    stateUpdated(CALL_MODE_BUTTON_PRESET);
  }

  setNightLightState(NightLightState::AutoOn);
}

void LumaCorePirBh1750Usermod::switchOffByPir()
{
  if (!isPirOwnedState()) return;

  setOneShotTransition(transitionSec);
  ownStateChange = true;

  if (bri > 0) {
    briLast = bri;
    bri = 0;
    stateChanged = true;
    stateUpdated(CALL_MODE_BUTTON_PRESET);
  }

  restorePreviousStateKeepingOff();
  setNightLightState(NightLightState::Idle);
}
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

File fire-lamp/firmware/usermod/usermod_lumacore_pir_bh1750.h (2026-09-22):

#pragma once

#include "wled.h"

#ifndef USERMOD_ID_LUMACORE_PIR_BH1750
#define USERMOD_ID_LUMACORE_PIR_BH1750 1001
#endif

#ifndef LUMACORE_PIR_PIN
#define LUMACORE_PIR_PIN 4
#endif

#ifndef LUMACORE_BH1750_SDA_PIN
#define LUMACORE_BH1750_SDA_PIN 16
#endif

#ifndef LUMACORE_BH1750_SCL_PIN
#define LUMACORE_BH1750_SCL_PIN 17
#endif

#ifndef LUMACORE_BH1750_ADDRESS
#define LUMACORE_BH1750_ADDRESS 0x23
#endif

#ifndef LUMACORE_LUX_READ_INTERVAL_MS
#define LUMACORE_LUX_READ_INTERVAL_MS 2000
#endif

#ifndef LUMACORE_PIR_ACTIVE_HIGH
#define LUMACORE_PIR_ACTIVE_HIGH 1
#endif

class LumaCorePirBh1750Usermod : public Usermod {
  private:
    enum class NightLightState : uint8_t {
      Disabled,
      Idle,
      AutoOn,
      WaitingOff,
      ManualOverride
    };

    static const char _name[];
    static const char _legacyName[];
    static const char _enabled[];
    static const char _luxThreshold[];
    static const char _offDelaySec[];
    static const char _transitionSec[];
    static const char _onPreset[];

    bool enabled = true;
    int8_t pirPin = LUMACORE_PIR_PIN;
    bool pirActiveHigh = LUMACORE_PIR_ACTIVE_HIGH != 0;
    float luxThreshold = 5.0f;
    uint16_t offDelaySec = 120;
    uint8_t transitionSec = 2;
    uint8_t onPreset = 2;
    int8_t sdaPin = LUMACORE_BH1750_SDA_PIN;
    int8_t sclPin = LUMACORE_BH1750_SCL_PIN;
    uint8_t bh1750Address = LUMACORE_BH1750_ADDRESS;
    uint16_t luxReadIntervalMs = LUMACORE_LUX_READ_INTERVAL_MS;

    bool initDone = false;
    bool pirPinAllocated = false;
    bool pirPinAllocationFailed = false;
    bool i2cPinsAllocated = false;
    bool sensorFound = false;
    bool luxValid = false;
    bool rawPirHigh = false;
    bool pirActive = false;
    bool lastPirActive = false;
    NightLightState nightLightState = NightLightState::Idle;
    bool ownStateChange = false;
    bool lastWledOn = false;
    bool previousStateSaved = false;
    bool restoreStateAfterManualOff = false;

    float lastLux = 0.0f;
    unsigned long lastPirCheck = 0;
    unsigned long lastLuxRead = 0;
    unsigned long offTimerStart = 0;
    char* previousStateJson = nullptr;
    size_t previousStateJsonLen = 0;
    byte previousCurrentPreset = 0;
    byte previousPresetCycCurr = 0;
    int16_t previousCurrentPlaylist = -1;

    bool initI2c();
    bool initBh1750();
    bool writeBh1750Command(uint8_t command);
    bool readBh1750Lux();
    bool capturePreviousState();
    bool restorePreviousStateKeepingOff();
    void clearPreviousState();
    void readPir();
    void handlePir();
    void switchOnByPir();
    void switchOffByPir();
    void setOneShotTransition(uint8_t seconds);
    bool isDark() const;
    bool isPirOwnedState() const;
    void setNightLightState(NightLightState newState);
    void releasePins(int8_t oldPirPin, int8_t oldSdaPin, int8_t oldSclPin, bool releasePirPin, bool releaseI2cPins);

  public:
    void setup() override;
    void loop() override;
    void onStateChange(uint8_t mode) override;
    void addToJsonInfo(JsonObject& root) override;
    void addToConfig(JsonObject& root) override;
    bool readFromConfig(JsonObject& root) override;
    uint16_t getId() override { return USERMOD_ID_LUMACORE_PIR_BH1750; }
};

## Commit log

2026-09-22 feat: publish Fire Lamp sources
    [LumaCore-S3-PWR.kicad_pcb]
2026-09-22 fix: restore Fire Lamp KiCad schematic
2026-09-22 fix: publish complete KiCad schematic
    [LumaCore-S3-PWR.kicad_sch]
2026-09-22 docs: add S3-PWR PCB renders
2026-09-22 docs: show PCB renders in Fire Lamp
2026-09-22 Добавить видео и STEP-сборку Fire Lamp R1.2
2026-09-22 Сохранить окончания строк README
2026-09-22 Добавить экспорт механики Fire Lamp R1.2
    [fire lamp.3mf, крышка.stl, плафон.stl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]
2026-09-22 Добавить галерею Fire Lamp для маркетплейса
2026-09-22 Разместить изображения непосредственно в media/images
2026-10-07 Update known issue description in README.md
    Reword known issue regarding ESP32-S3 restarts and capacitor C14.
2026-11-04 pcb: publish C14 100 uF update and portable KiCad libraries
2026-11-04 Update README to remove C14 capacitor details
    Removed outdated information regarding C14 capacitor testing and issues.
2026-11-07 feat(sunflower): publish night-light CAD, print files and BOM
    Publish the Sunflower night-light alongside Fire Lamp with reference STEP, seven printable STL models, Bambu Studio project, BOM, construction notes and visualizations. Document STEP/print difference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
2026-11-07 docs(sunflower): specify Ozon switch and Ecola lamp
2026-11-07 docs(sunflower): rename print folder to 3d-printing
2026-11-07 docs(sunflower): consolidate printable files in stl folder
2026-11-07 docs(fire-lamp): move printable files into stl folder
